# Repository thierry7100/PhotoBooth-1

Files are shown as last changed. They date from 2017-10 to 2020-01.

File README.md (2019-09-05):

A PhotoBooth for special events like wedding.

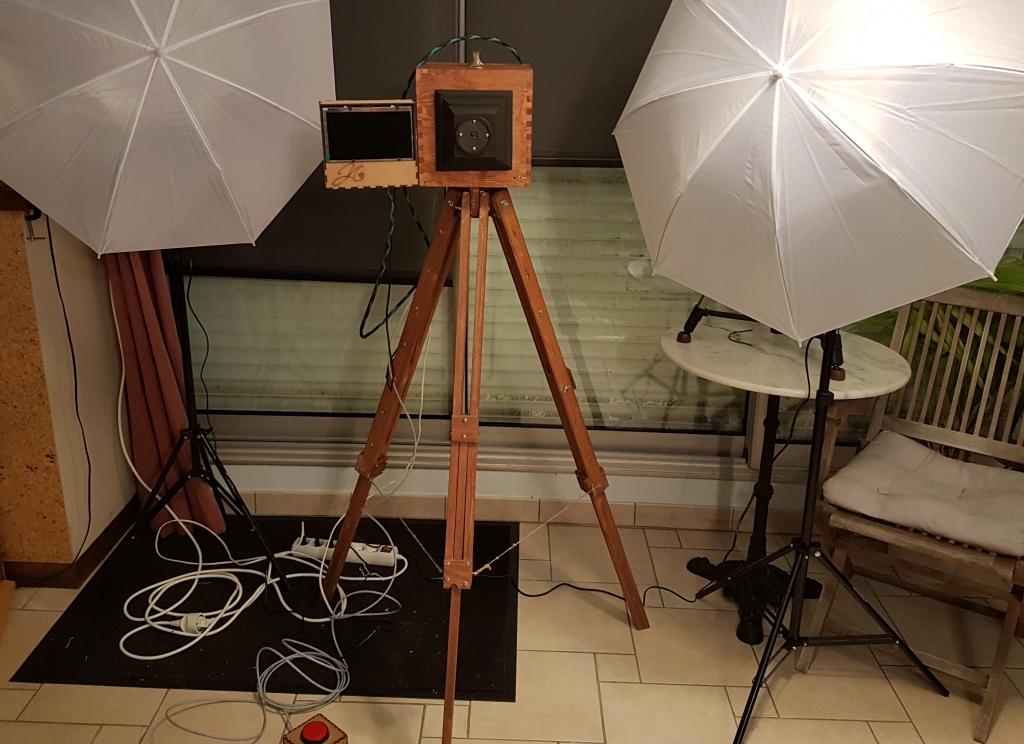
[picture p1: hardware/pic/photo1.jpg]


## Usage
Live video is displayed on the screen. The big red buton is slowly flashing. When pressed, the screen display a countdown and the picture is taken. Then the captured photo is displayed on the screen.
At the end, it is saved in the home directory and uploaded to a google drive if network is available.

A small button can be used to :
* restart software (short press)
* power off RPi (long press)
* power on the pi (short press when off)

A led strip can be controled by the PhotoBooth to add light during countdown and picture shooting.

## Firmware
Based on a standard Raspbian distribution with some python software.

See readme in [subdir](firmware/) for details.

## Hardware

Bill Of material :
* 1 RaspberryPi 3
* 1 Raspberry Pi Camera v2
* 1 52pi 7 inches [screen](https://wiki.52pi.com/index.php/7-Inch-1024x600_Display_Kit_(without_Touch_Screen)_SKU:Z-0051)
* 1 [Big red button](https://www.aliexpress.com/item/5-Colors-LED-Light-Lamp-60MM-Big-Round-Arcade-Video-Game-Player-Push-Button-Switch/32794775928.html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) for picture shooting
* 1 arcade button for software control

See readme in [subdir](hardware/) for details.

## tips for post-treatment
Picture are mirorred, to revert to normal :
```
mogrify -flop *.jpg
```
If running windows, download ImageMagick for Windows then command is :
```
magick.exe mogrify -flop *.jpg
```

In case of bad date and so a bad name. (with no RTC on the pi)
Let's say a picture is taken 22/03/2018 at 16:30, but dated 04/03/2018 at 17:48
```
jhead -da2018:03:22/16:30-2018:03:04/17:48 *.jpg
jhead -ft *.jpg
jhead -nf%Y%m%d-%H%M%S *.jpg
```

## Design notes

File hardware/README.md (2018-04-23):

Here's the hardware part of the PhotoBooth.

## doc
Some documentation about the used parts
* screen board
* Raspberry Pi Camera v2.1

## elec
This is the schematic of the electronic part.

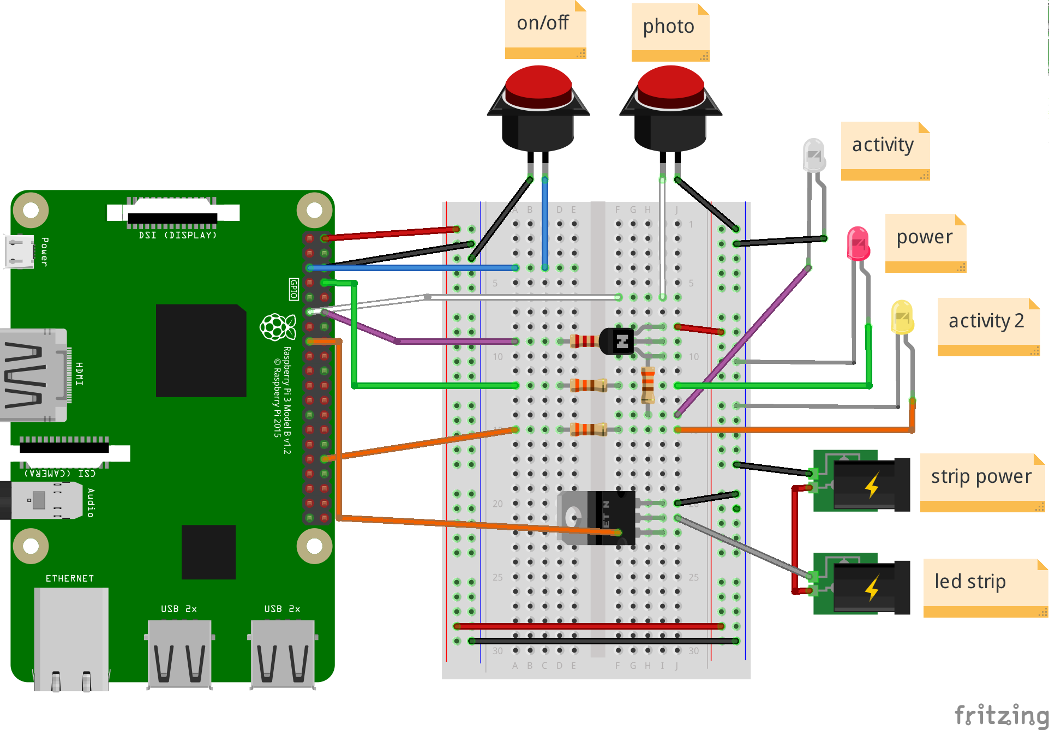
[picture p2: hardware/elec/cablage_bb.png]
scheme Scheme


* on/off : small button for software control
* photo : big red button
* activity/activity2 : led that will be pulsed (slow when waiting, fast during countdown)
* power : power led
* strip power : input power for a "flash" led strip
* led strip : controled power output for the led strip

## meca
Some 3D printed or laser cutted parts :
* button_box : laser cutted box for the big red button
* ecran : 3D printed brackets to hold the screen and its board
* flash : laser cutted box for the screen (use with ecran brackets)
* led_support : 3D printed support for a specific microphone leg
* objectif : 3D printed plate to mimic a camera lens and hold the RPi camera
* plaque : 3D printed decoration badge

## meca_52pi
3D printed brackets to easily hold the screen and its board on a desk.
See [Thingiverse](https://www.thingiverse.com/thing:2614797) for details.

## pic
Pictures of the final PhotoBooth

## other
* sign : laser cutted lighted sign for the photobooth

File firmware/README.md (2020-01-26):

## Software
* PhotoBooth_3Img_mariage.py : PhotoBooth main daemon. handle taking picture and upload to google drive
* listen-for-shutdown.py : management software :
  * starting/stopping camera_btn.py (short press)
  * powering off RPi (long press)
* *.service : systemctl services definition

## Install

Based on [Raspbian](https://www.raspberrypi.org/downloads/raspbian/)

Install shutdown service

    sudo cp listen-for-shutdown.service /etc/systemd/system/
    sudo systemctl daemon-reload
    sudo systemctl enable listen-for-shutdown.service
    sudo systemctl start listen-for-shutdown.service

Install Photobooth service

    sudo cp photobooth.service /etc/systemd/system/
    sudo systemctl daemon-reload
    sudo systemctl enable photobooth.service
    sudo systemctl start photobooth.service

Install needed python modules

    pip install --upgrade google-api-python-client

get api ID clients OAuth 2.0 client_id.json and put in current directory. See https://console.developers.google.com/apis/credentials

## Customization
There's some images displayed by the PhotoBooth service. They are overlayed on top of the live image.
The documentation explains how to change these images

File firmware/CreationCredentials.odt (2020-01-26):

Credentials Google drive API

1. Se connecter sur son compte Google via le navigateur
2. Aller sur https://developers.google.com/drive/api/v3/quickstart/python
3. Cliquer sur Enable Drive API, cela génère un fichier credentials.json qui va être ensuite utilisé pour accéder au service
4. Ce fichier doit être stocké dans le photo booth et référencé dans le fichier photoBooth.cfg par l’entrée SecretFile
5. Dans la même page, le logiciel python QuickStart.py permet de générer la clef. Vous pouvez donc le faire « OffLine ». Mais cette génération est également intégrée au logiciel PhotoBooth. Sur Raspberry il faut néanmoins que le navigateur soit ouvert pour créer ce fichier (le navigateur ne se lance pas directement). Bien sûr ceci n’est nécessaire que la première fois, ensuite si le fichier est présent il sera utilisé. Identifiez vous avec votre compte Google et le fichier d’accès est créé, avec PhotoBooth il est directement stocké dans le répertoire ~/.credentials où il sera utilisé. Référencez le fichier créé dans le fichier photoBooth.cfg par l’entrée CredentialFile

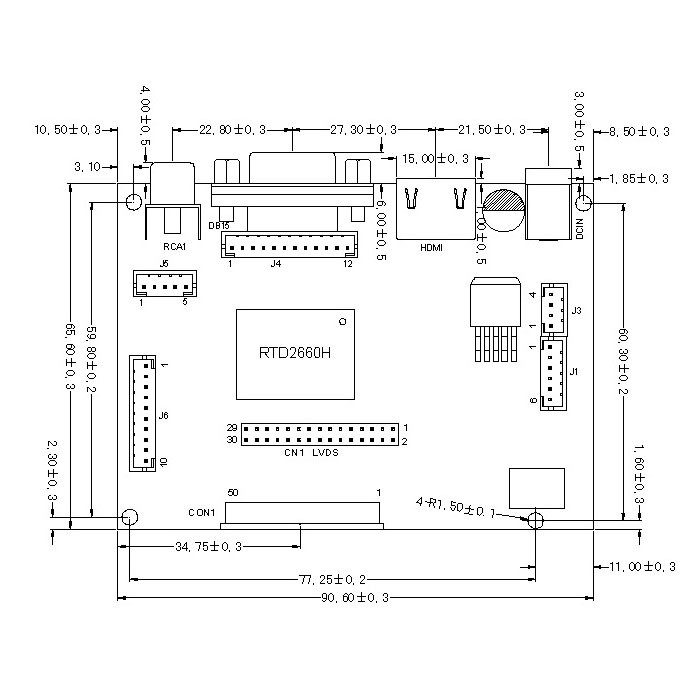
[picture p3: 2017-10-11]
hardware/doc/Outlinedrawing_7_1_1_1.jpg

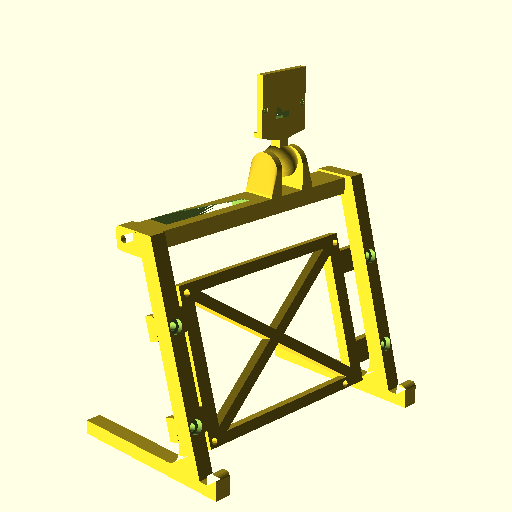
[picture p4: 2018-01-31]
hardware/meca_52pi/model.png

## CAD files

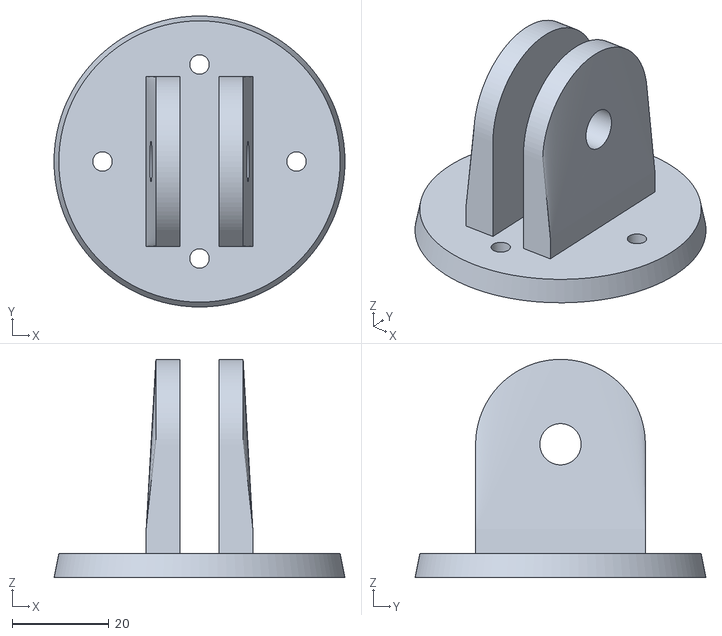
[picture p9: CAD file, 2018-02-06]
hardware/meca/led_support.stl
60.0 x 60.0 x 45.0

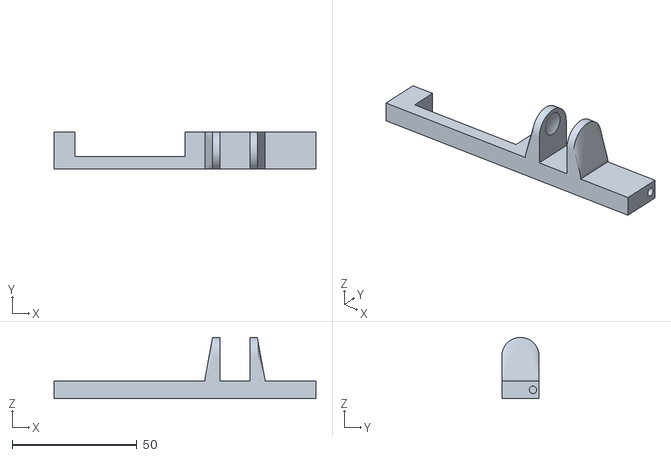
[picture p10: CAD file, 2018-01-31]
hardware/meca_52pi/barre.stl
105.0 x 15.0 x 24.5

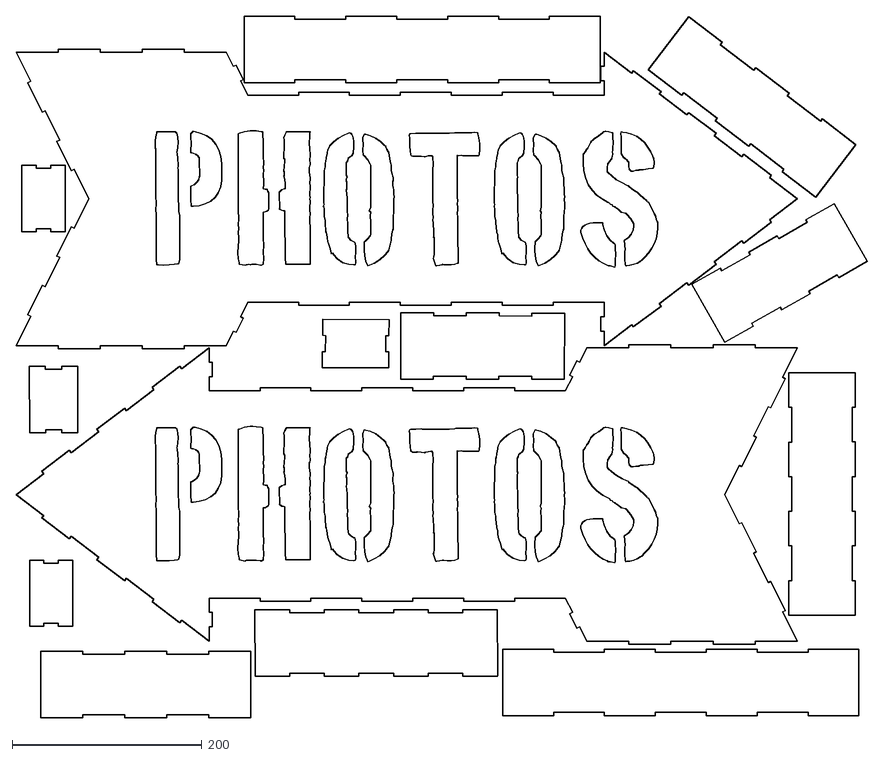
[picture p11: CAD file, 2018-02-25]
hardware/sign.dxf
896.4 x 738.6

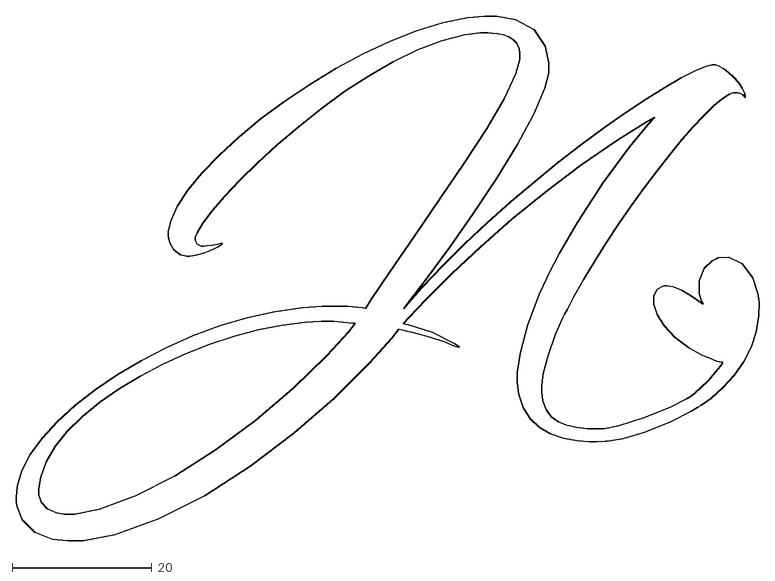
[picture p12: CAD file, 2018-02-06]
hardware/meca/logo.dxf
106.5 x 75.2

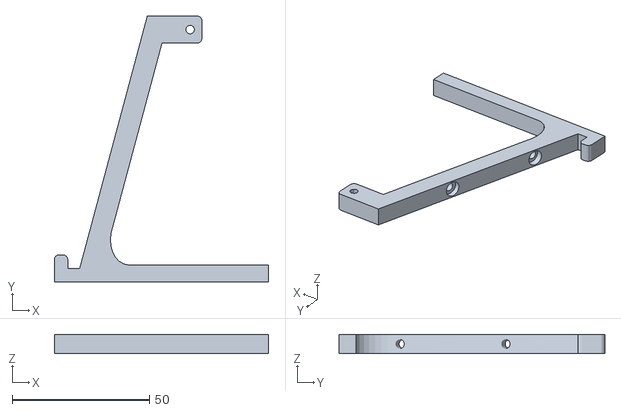
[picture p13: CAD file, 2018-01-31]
hardware/meca_52pi/pied.stl
78.1 x 96.9 x 7.00

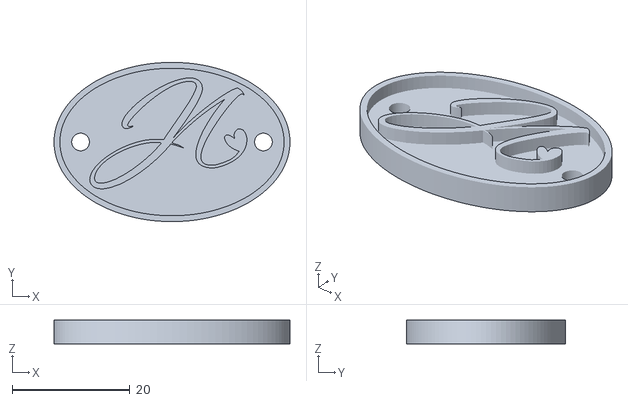
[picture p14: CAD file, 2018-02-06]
hardware/meca/plaque.stl
40.0 x 27.0 x 4.00

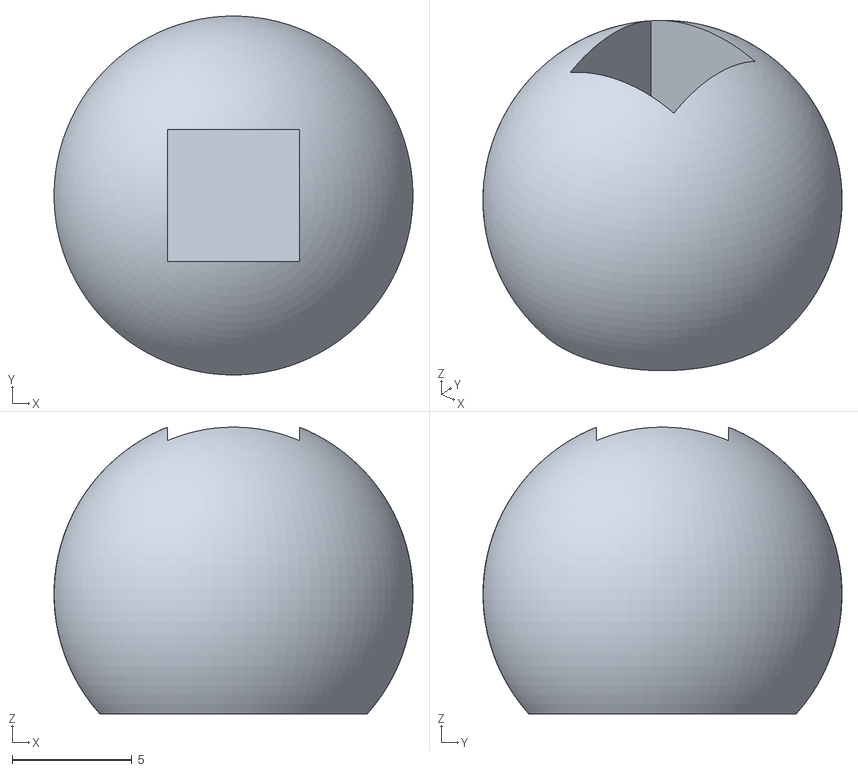
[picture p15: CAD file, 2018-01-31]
hardware/meca_52pi/camera.stl
15.0 x 15.0 x 12.0

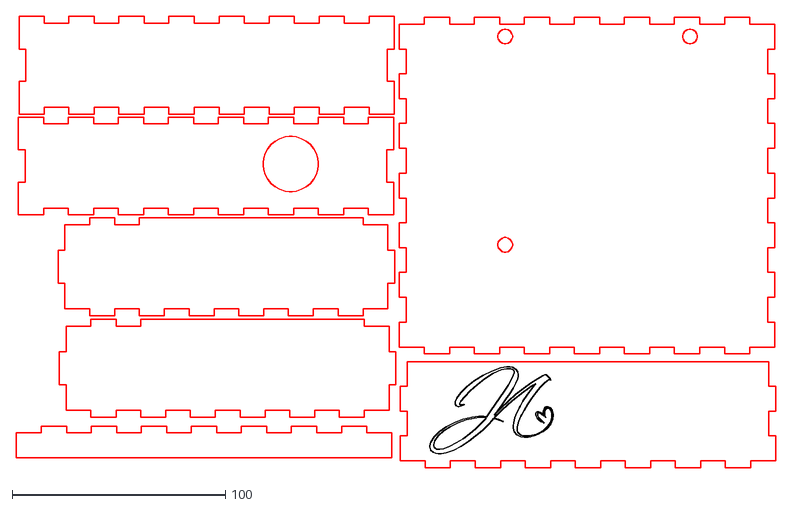
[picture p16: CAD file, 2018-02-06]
hardware/meca/flash.dxf
356.1 x 211.7

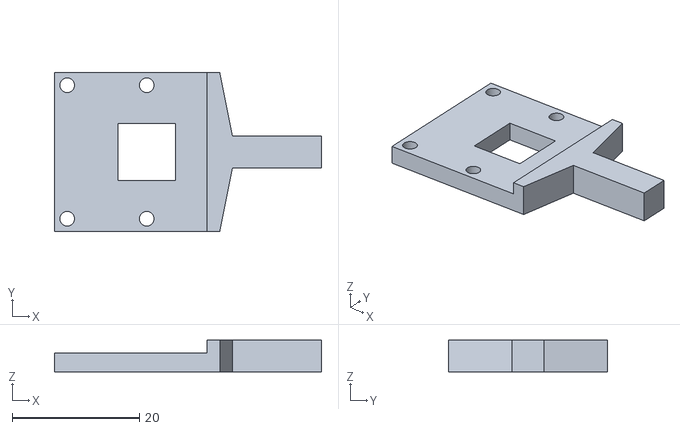
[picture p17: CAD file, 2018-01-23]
hardware/meca_52pi/camera_support.stl
42.0 x 25.0 x 5.00

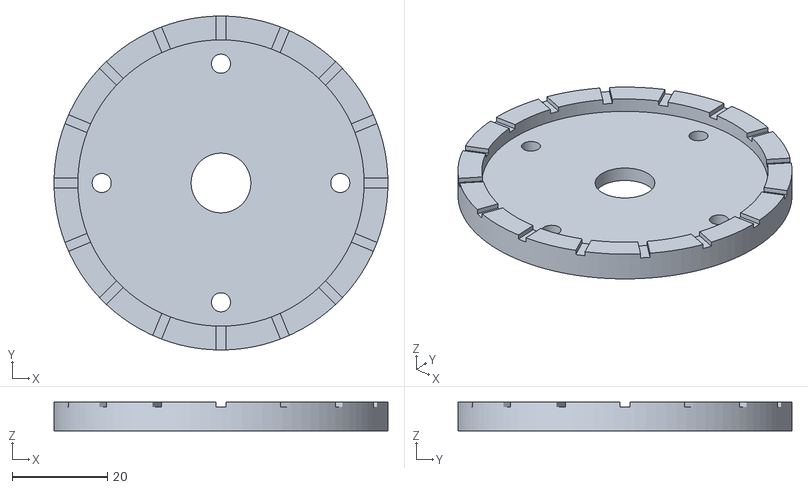
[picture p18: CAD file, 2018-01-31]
hardware/meca/objectif.stl
70.0 x 70.0 x 6.00

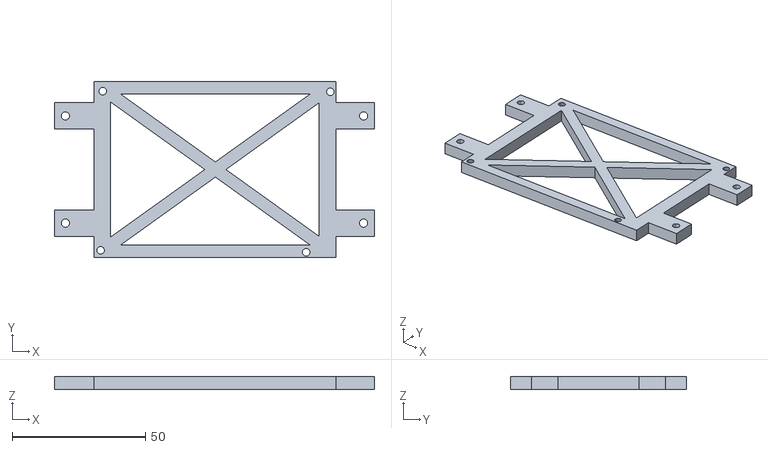
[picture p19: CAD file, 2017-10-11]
hardware/meca_52pi/support.stl
120.0 x 65.9 x 5.00

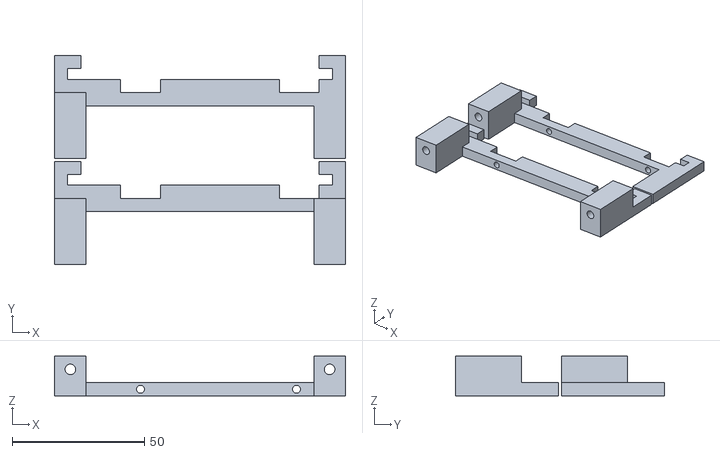
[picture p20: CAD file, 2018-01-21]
hardware/meca/ecran.stl
110.0 x 79.0 x 15.0

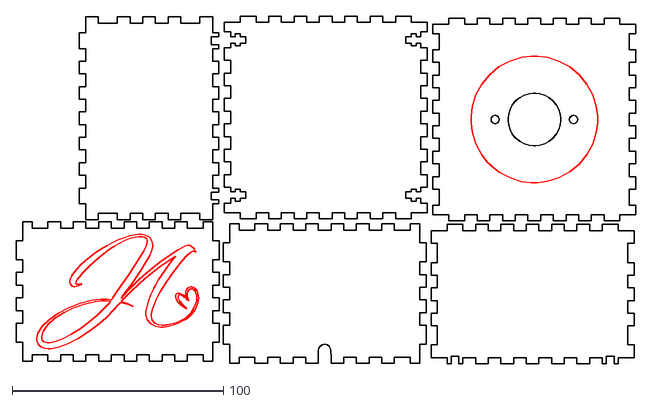
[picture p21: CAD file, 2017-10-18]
hardware/meca/button_box.dxf
293.1 x 164.6

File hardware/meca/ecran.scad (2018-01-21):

// support ecran+carte
$fn=100;

// crochet pour retenir l'écran
module crochet() {
	translate ([0,0, 0]) cube ([5, 9, 5]);
	translate ([5,4,0])  cube ([5, 5, 5]);
}

// attaches vers le boitier
module attache() {
	difference() {
		translate ([0,-25,0]) cube ([12, 25, 15]);
		translate([6,0,10]) rotate([90,0,0]) cylinder(d=4, h=27);
	}

}

// trous d'attache pour la carte
module carte() {
rotate([90,0,0]) cylinder (d=3, h=7);
translate([59,0,0]) rotate([90,0,0]) cylinder (d=3, h=7);
}

// support
module support() {
	union() {
		difference() {
			cube ([110, 5, 5]); // barre ppale
			translate ([25,0,0]) cube ([15, 5, 5]);
			translate ([85,0,0]) cube ([15, 5, 5]);
		}
		difference () { // barre d'écartement
			translate ([0,-5,0]) cube ([110, 5, 5]);
			translate([32.5, 0, 2.5]) carte();
		}
		translate([0,0,0]) attache();
		translate([98,0,0]) attache();
		translate ([0,5,0]) crochet();
		translate([110,5,0]) mirror ([1,0,0]) crochet();
	}
}

support();
// 2eme support avec decoupe pour prise d'alim
translate([0,40,0]) {
	difference() {
		support();
		translate([95,-25,5]) cube ([20,25,16]);
	}
}

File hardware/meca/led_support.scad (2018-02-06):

/** attache sur pied micro */

$fn=100;

// base
base_diam = 60; // diametre du bas
base_haut = 5; // hauteur

// support
sup_larg = 35; // largeur
sup_haut = 40; // hauteur totale
sup_ep = 5; // epaisseur au plus fin (en haut)
sup_trou = 8.5; // diametre du trou de vis
sup_int = 8; // interval entre les 2 supports

// base
module base () {
	cylinder (d1=base_diam, d2=base_diam-2, h=base_haut);
}

// 1 support
module support() {
	difference() {
		hull() {
			translate([-1,0,0]) cube ([sup_haut-sup_larg+1, sup_larg, sup_ep+2]); // base du support
			translate([sup_haut-sup_larg/2,sup_larg/2,0]) cylinder (d=sup_larg, h=sup_ep); // haut du support
		}
		translate([sup_haut-sup_larg/2,sup_larg/2,-1]) cylinder (d=sup_trou, h=sup_ep+4); // trou de fixation
	}
}

// objet complet
difference() {
	union() {
		base();
		translate([(sup_int/2),sup_larg/2,base_haut]) rotate([0,-90,180]) support();
		translate([-(sup_int/2),-sup_larg/2,base_haut]) rotate([0,-90,0]) support();
	}
	// trous de fixation de la base
	for (i = [0:360/4:360] ) {
		rotate (a = [0,0,i]) translate ([base_diam/3, 0, -1]) cylinder (d=4, h=base_haut+2);
	}
}

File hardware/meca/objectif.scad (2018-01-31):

$fn=100;

module facade() {
	difference() {
		cylinder (d=70, h=3); // facade
		translate ([0, 0, -1]) cylinder (d=12.5, h=5); // trou objectif
		// trous fixation
		translate ([-12.5, -10.5, -1]) cylinder (d=2.3, h=3.5);
		translate ([-12.5, 10.5, -1]) cylinder (d=2.3, h=3.5);
		translate ([0, -10.5, -1]) cylinder (d=2.3, h=3.5);
		translate ([0, 10.5, -1]) cylinder (d=2.3, h=3.5);
		fixations();
	}
}

// indentations bague
module bague_ident() {
	for (i = [0:22.5:360] ) {
		rotate (a = [0,0,i]) translate([-1, 27, 5]) cube ([2, 12, 2]);
	}
}

module bague() {
	difference() {
		translate ([0, 0, 3]) cylinder (d=70, h=3); // facade
		translate ([0, 0, 2]) cylinder (d=60, h=5); // facade
		bague_ident();
	}

}

// trous de fixation
module fixations() {
	for (i = [0:360/4:360] ) {
		rotate (a = [0,0,i]) translate ([-25,0,-1]) cylinder (d=4, h=5);
	}
}

module logo() {
	linear_extrude(height=4) {
		import(file="logo.dxf");
	}
}

union() {
	facade();
	bague();
// 	translate ([15/2+35/2,-10,0]) rotate([0,0,90]) resize ([20,15]) logo();
}

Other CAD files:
hardware/meca/plaque.scad
hardware/meca_52pi/model.scad
hardware/meca_52pi/pied.dxf
hardware/meca_52pi/support.dxf

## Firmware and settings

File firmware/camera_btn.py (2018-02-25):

#!/usr/bin/python

from __future__ import print_function
import httplib2
import os, sys

from picamera import PiCamera
from time import *
from gpiozero import Button, LED, PWMLED
from PIL import Image

from apiclient import discovery
from oauth2client import client
from oauth2client import tools
from oauth2client.file import Storage
from apiclient.http import MediaFileUpload
from apiclient.discovery import build
from threading import Thread

# If modifying these scopes, delete your previously saved credentials
# at ~/.credentials/drive_photobooth.json
SCOPES = 'https://www.googleapis.com/auth/drive.file'
CLIENT_SECRET_FILE = 'client_id.json'
APPLICATION_NAME = 'PhotoBooth'


button = Button(17)
led = PWMLED(18)
led2 = PWMLED(12)
camera = PiCamera()
ledStrip = LED(22)

camera.resolution = (2592, 1944)
camera.annotate_text_size = 160
camera.hflip = True # horizontal flip to see as in a mirror
# this is not Needed, just add display_rotate=2 or lcd_rotate=2 in /boot/config.txt
camera.vflip = False # vertical flip if screen is upside down

def get_credentials():
	"""Gets valid user credentials from storage.

	If nothing has been stored, or if the stored credentials are invalid,
	the OAuth2 flow is completed to obtain the new credentials.

	Returns:
		Credentials, the obtained credential.
	"""
	home_dir = os.path.expanduser('~')
	credential_dir = os.path.join(home_dir, '.credentials')
	if not os.path.exists(credential_dir):
		os.makedirs(credential_dir)
	credential_path = os.path.join(credential_dir,
											'drive_photobooth.json')

	store = Storage(credential_path)
	credentials = store.get()
	if not credentials or credentials.invalid:
		flow = client.flow_from_clientsecrets(CLIENT_SECRET_FILE, SCOPES)
		flow.user_agent = APPLICATION_NAME
		if flags:
			credentials = tools.run_flow(flow, store, flags)
		else: # Needed only for compatibility with Python 2.6
			credentials = tools.run(flow, store)
		print('Storing credentials to ' + credential_path)
	return credentials

def uploadToDrive (fname):
	credentials = get_credentials()
	http = credentials.authorize(httplib2.Http())
	service = discovery.build('drive', 'v3', http=http)

	results = service.files().list(
		pageSize=10,fields="nextPageToken, files(id, name)").execute()
	items = results.get('files', [])
	if not items:
		print('No files found.')
	else:
		print('Files:')
		folder_id = None;
		for item in items:
			print('{0} ({1})'.format(item['name'], item['id']))
			if item['name'] == "PhotoBooth":
				folder_id = item['id']
		if not folder_id:
			# create dir
			file_metadata = {
				'name': 'PhotoBooth',
				'mimeType': 'application/vnd.google-apps.folder'
			}
			file = service.files().create(body=file_metadata,
															fields='id').execute()
			print ('Created Folder ID: %s' % file.get('id'))
			folder_id = file.get('id')
		# upload file
		file_metadata = {
			'name': os.path.basename(fname),
			'parents': [folder_id]
		}
		media = MediaFileUpload(fname,
										mimetype='image/jpeg',
										resumable=True)
		file = service.files().create(body=file_metadata,
														media_body=media,
														fields='id').execute()
		print ("Created File : %s (%s)" % (file.get('name'), file.get('id')))

def getImg (fname):
	# Load the arbitrarily sized image
	img = Image.open(fname)
	# Create an image padded to the required size with
	# mode 'RGB'
	#print img.size
	pad = Image.new('RGBA', (
		((img.size[0] + 31) // 32) * 32,
		((img.size[1] + 15) // 16) * 16,
		))
	# Paste the original image into the padded one
	pad.paste(img, (0, 0))
	return pad

class thUpload(Thread):
	def __init__(self, fname):
		Thread.__init__(self)
		self.fname = fname
	def run (self):
		try:
			uploadToDrive ( self.fname )
		except:
			print ("cannot upload picture %s to drive. (%s)" % (outfile, sys.exc_info()[0]) , file=sys.stderr)


acc = getImg ("Accueil.png")
merci = getImg ("Merci.png")
waits = []
for i in range(3):
	waits.append(getImg ("%d.png" % (i+1)))

camera.start_preview()
while True:
	try:
		# Add the overlay with the padded image as the source,
		# but the original image's dimensions
		# note: we need to hflip the overlay only if vfliped
		o = camera.add_overlay(acc.tobytes(), format='rgba', vflip=camera.vflip, hflip=camera.vflip)
		# By default, the overlay is in layer 0, beneath the
		# preview (which defaults to layer 2). Here we make
		# the new overlay semi-transparent, then move it above
		# the preview
		#o.alpha = 128
		o.layer = 3

		led.pulse(2,2)
		button.wait_for_press()

		camera.remove_overlay(o)

		ledStrip.on()

		#led.blink (on_time=0.125, off_time=0.125, n=16, background=True)
		#led2.blink (on_time=0.125, off_time=0.125, n=16, background=True)
		# blink leds to show waiting time
		led2.pulse (fade_in_time=0.125, fade_out_time=0.125, n=16, background=True)
		led.pulse (fade_in_time=0.125, fade_out_time=0.125, n=16, background=True)

		# show countdown on top of camera
		for i in range(2, -1, -1):
			#led.value = 0
			o = camera.add_overlay(waits[i].tobytes(), format='rgba', layer=3, vflip=camera.vflip, hflip=camera.vflip)
			sleep(1)
			nblink = 3-i
			#print (nblink, ", ", 1.0/(2**nblink))
			#led.blink (on_time=1.0/(2**nblink), off_time=1.0/(2**nblink), n=nblink, background=False)
			camera.remove_overlay(o)
		# capture still image from camera
		outfile = '/home/pi/Pictures/%s.jpg' % ( strftime("%Y%m%d-%H%M%S", localtime() ) )
		led.value = 1
		led2.value = 1
		camera.capture( outfile )
		#print outfile

		ledStrip.off()
		led.value = 0
		led2.value = 0
		# show thank you, here's your picture
		o = camera.add_overlay(merci.tobytes(), format='rgba', layer=3, vflip=camera.vflip, hflip=camera.vflip)
		sleep(2)
		# show captured picture
		outover = getImg (outfile)
		camera.remove_overlay(o)
		o = camera.add_overlay(outover.tobytes(), format='rgba', layer=3)
		#camera.annotate_text = 'Voici votre Photo ...\nMerci'
		sleep(4)
		camera.remove_overlay(o)
		# upload picture to google drive
		th = thUpload (outfile)
		th.start()
		# th.join() # do not wait for uploading thread
		print ("upload")
	except KeyboardInterrupt:
		camera.stop_preview()
		break



camera.stop_preview()

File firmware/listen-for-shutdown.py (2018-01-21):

#!/usr/bin/env python

# press/release quickly button for start/stop photobooth service
# hold button for >2s for shutdown


from gpiozero import Button
from subprocess import check_call, CalledProcessError, STDOUT
from signal import pause
import os

shutdown_btn = Button(3, hold_time=2)
FNULL = open(os.devnull, 'w')

def shutdown():
	#print ("btn held")
	check_call(['poweroff'])

def stop_start():
	#print ("btn released")
	try:
		check_call(['systemctl', 'status', 'photobooth.service'])
		# no error, service is running, stop it
		#print("Stopping photobooth")
		check_call(['systemctl', 'stop', 'photobooth.service'])
	except CalledProcessError:
		# error, service is not running, start it
		#print("Starting photobooth")
		check_call(['systemctl', 'start', 'photobooth.service'])

# GPIO.setup(3, GPIO.IN, pull_up_down=GPIO.PUD_UP)
# GPIO.wait_for_edge(3, GPIO.FALLING)

shutdown_btn.when_held = shutdown
shutdown_btn.when_released = stop_start

pause()

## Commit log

2017-10-11 initial import
    [barre.scad, barre.stl, pied.dxf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]
2017-10-11 move scad models to one single file add xport script
    [barre.scad, barre.stl, model.scad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]
2017-10-11 Update support de boule
    [barre.stl, model.scad]
2017-10-11 1ere version support camera
    [model.scad]
2017-10-11 new housing for rpi camera v2
    [barre.stl, camera.stl, model.scad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]
2017-10-14 update doc & add scheme
    [cablage.fzz]
2017-10-14 Add blinking led
2017-10-15 Add 2nd activity led
2017-10-18 add box for red button
    [button_box.dxf]
2017-10-21 update cabling colors
    [cablage.fzz]
2017-10-25 Ajout transistor for led activity
    [cablage.fzz]
2018-01-07 Add led strip control
2018-01-07 Update connections after protoboard making
    [cablage.fzz, model.scad]
2018-01-07 Add photobooth start/stop function to power button
2018-01-21 3Dprinted meca for screen & objectif
    [ecran.scad, ecran.stl, objectif.scad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]
2018-01-23 bugfix: also export camera_support.stl
    [camera_support.stl, model.scad]
2018-02-04 flip screen as it is upside down
    [camera_btn.py]
2018-02-06 modif flash box
    [flash.dxf]
2018-02-06 add led light support & deco plaque
    [led_support.scad, led_support.stl, logo.dxf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]
2018-02-25 enseigne lumineuse
    [sign.dxf]
2020-01-26 Add files via upload
    Soft modifié : impression, fichier configuration, overlay avec résolution écran
    [photoBooth.cfg]
